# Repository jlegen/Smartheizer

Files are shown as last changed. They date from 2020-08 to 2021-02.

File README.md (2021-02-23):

# Smartheizer
## basic heating control

 I wanted some more control for my ancient heating system:
 * enable heating remotely before returning from holidays in winter :-)
 * record activity of heating system and hot water preparation
 * embed into my <a href="https://iobroker.net"> iobroker</a> system

 ##  The hardware in short:

* provides 3 isolated inputs for recording operation times (oil burner, pumps, hot water preparation)
* 3 relays to control heating operations, night setback remotely
* 3 plugs for DS18B20 temperature sensors
* socket for Wemos D1 Mini (or Pro)
* runs with <a href="https://tasmota.github.io/docs/"> Tasmota</a>

## Software needed
* Tasmota for the Wemos D1 on the PCB, which handles the GPIO inputs, Relays and temperature sensors
* a MQTT broker running somewhere, or a smart home software like iobroker or home assistant with MQTT enabled

## Tasmota config

Wemos D1 configuration in Tasmota:

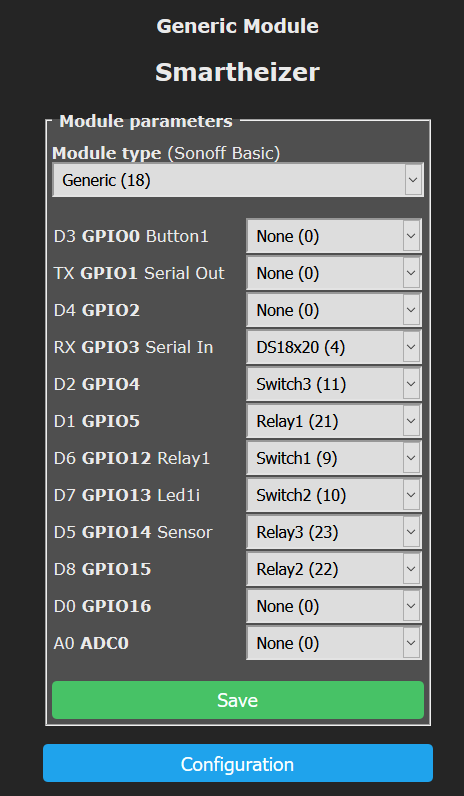
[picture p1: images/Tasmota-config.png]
Tasmota Wemos Config


Some Tasmota configurations can be easily applied using the web console. 

1) The GPIO polarity needs to be fixed:
<pre>
Backlog Switchmode1 2; Switchmode2 2; Switchmode3 2
</pre>

2) You also need to decouple the "Switches" (which are the GPIO inputs) from the Relays (it seems like a sort of 'tradition' with tasmota, that per default "Switch1" always triggers "Relay1" etc.).
<pre>
Rule1 on Switch1#state do Publish tele/tasmota_6E171C/SENSOR {"Time":"%timestamp%", "Burner":"%value%"} endon on Switch2#state do Publish tele/tasmota_6E171C/SENSOR {"Time":"%timestamp%", "Pump1":"%value%"} endon on Switch3#state do Publish tele/tasmota_6E171C/SENSOR {"Time":"%timestamp%", "Pump2":"%value%"} endon

Rule1 1
</pre>

Of course, you may chose different topics for MQTT. 
Btw, you don't even need to use these topics with your iobroker or other software - defining the "Rule1" alone enables Tasmota to send the switch states with MQTT as well.

New PCB revision
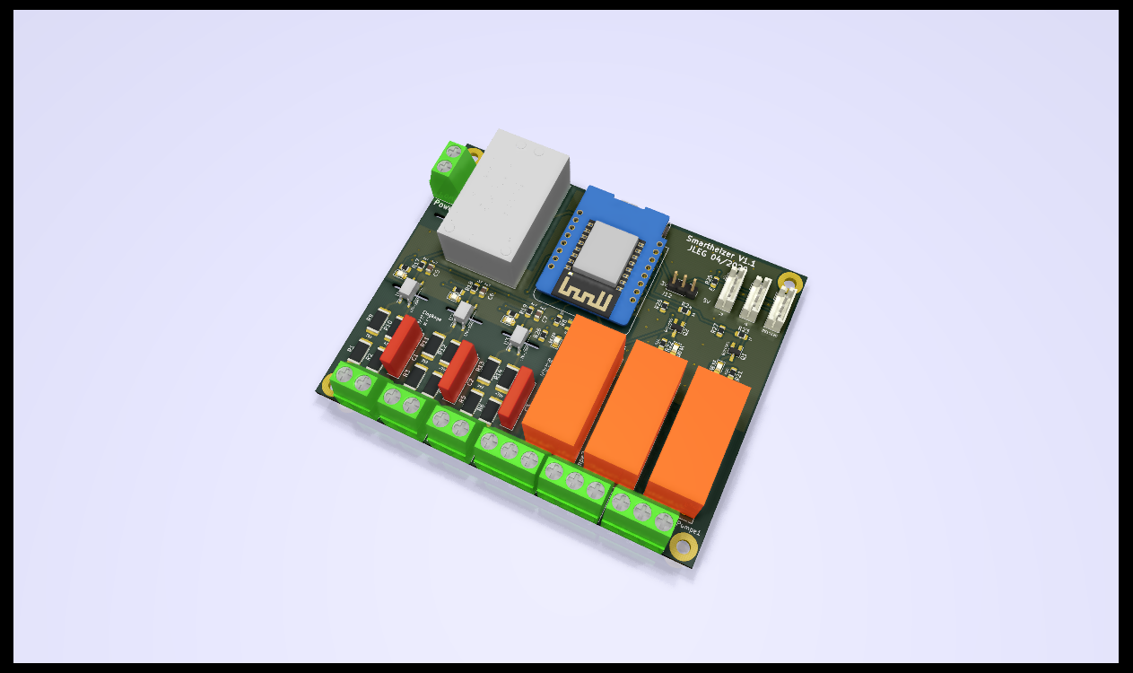
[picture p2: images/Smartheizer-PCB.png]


It works! :-)
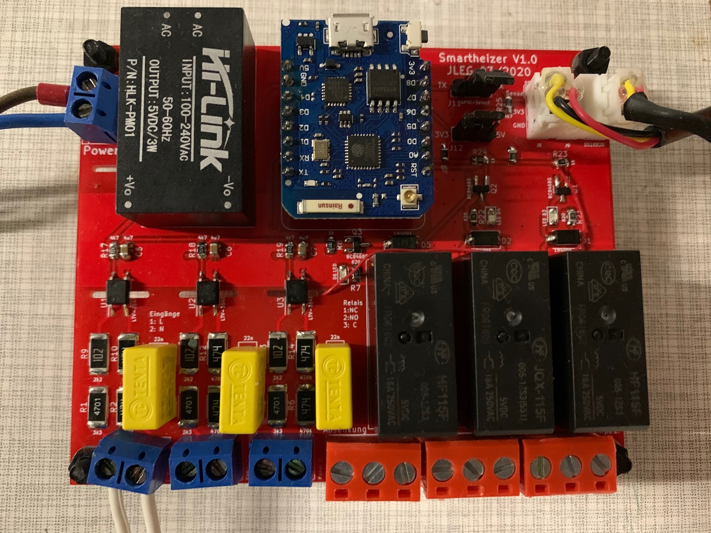
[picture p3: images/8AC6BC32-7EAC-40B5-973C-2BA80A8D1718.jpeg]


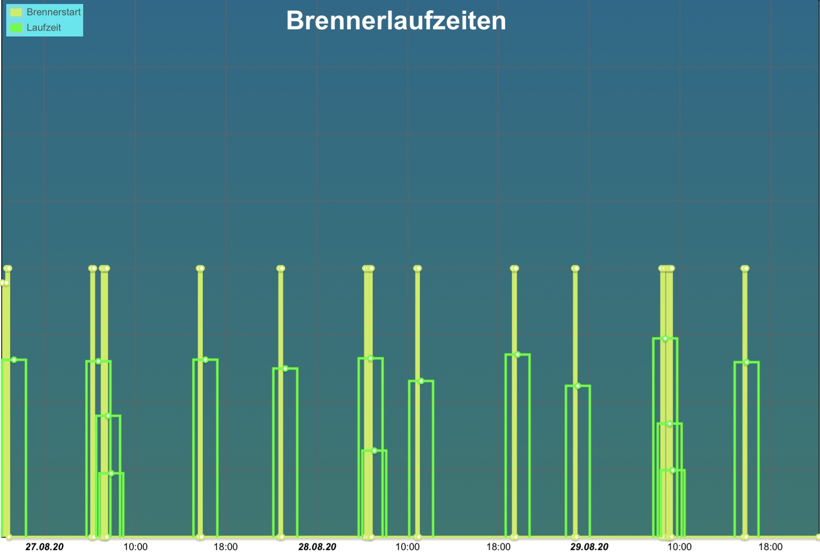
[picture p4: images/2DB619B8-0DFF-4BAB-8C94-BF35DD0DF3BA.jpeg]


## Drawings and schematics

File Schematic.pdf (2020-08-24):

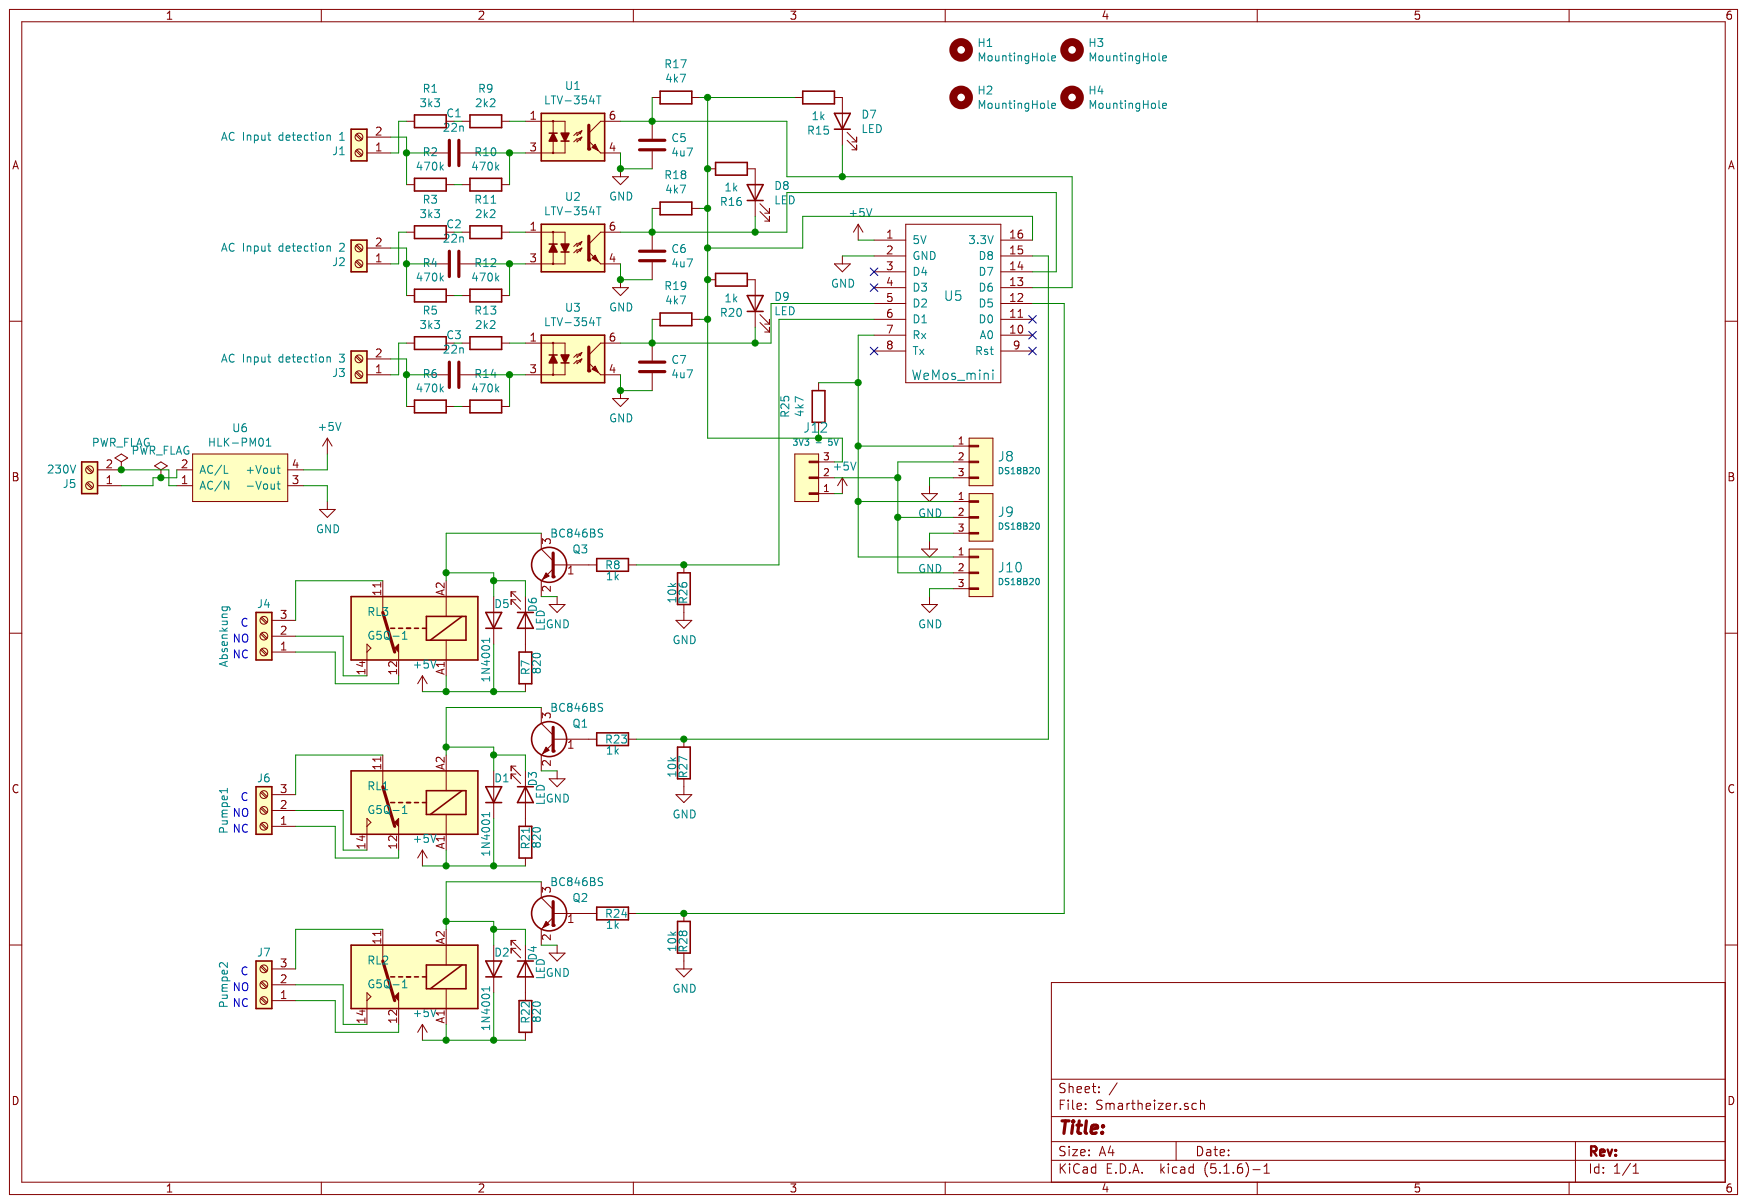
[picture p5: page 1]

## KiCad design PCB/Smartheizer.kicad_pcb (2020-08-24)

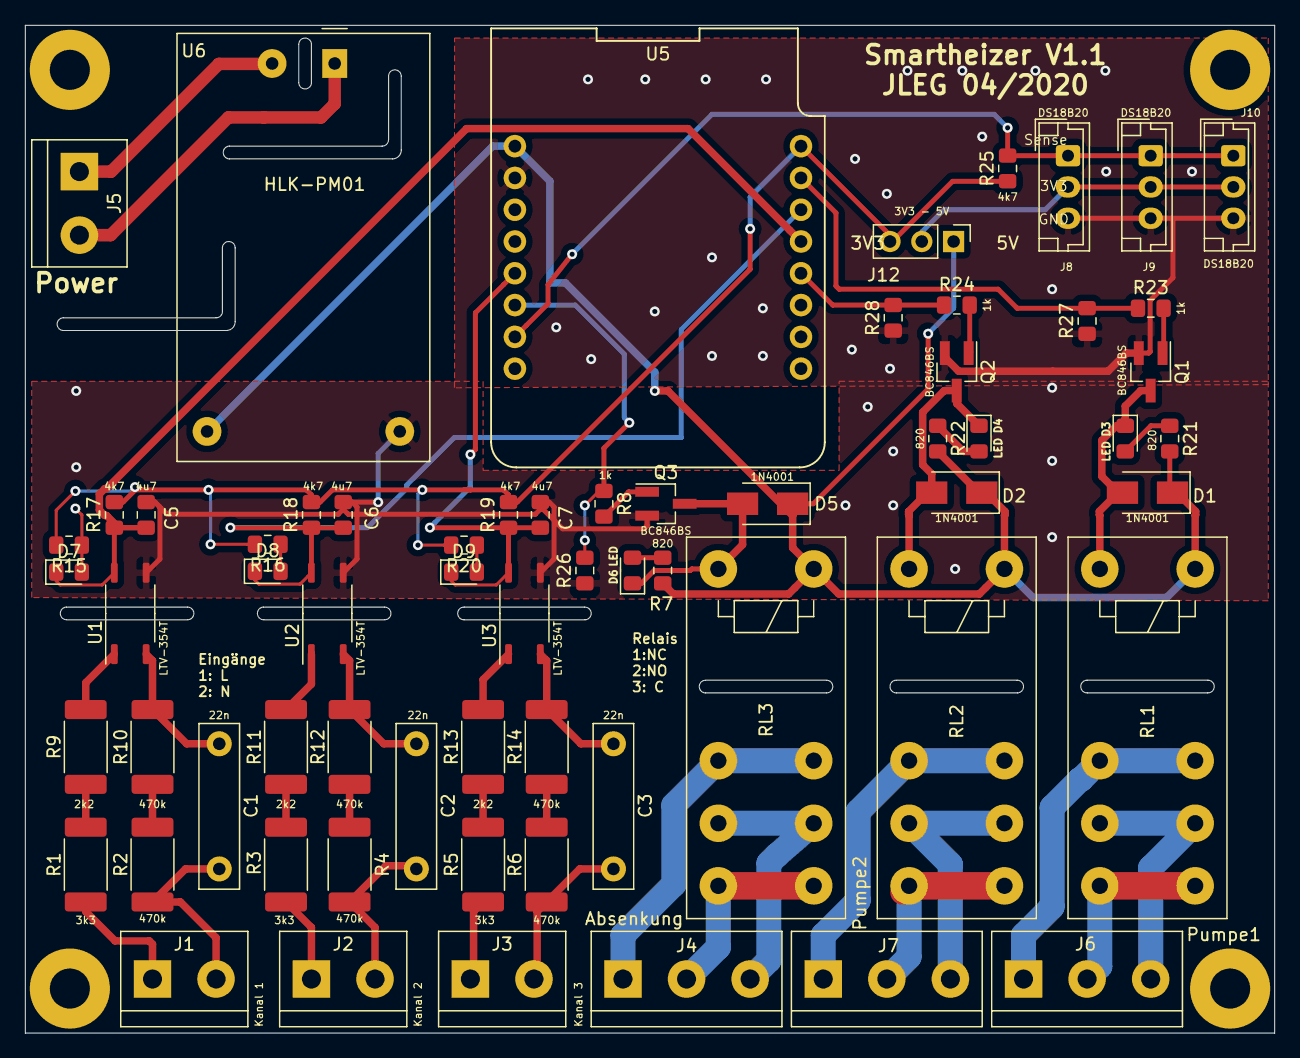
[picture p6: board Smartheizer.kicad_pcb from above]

Board: 2 copper layers, 99.8 x 80.5 mm, 69 parts (0 on the bottom side), 52 nets.

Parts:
C1, C2, C3: 22n; C_Rect_L13.0mm_W3.0mm_P10.00mm_FKS3_FKP3_MKS4
C5, C6, C7: 4u7; C_0805_2012Metric_Pad1.15x1.40mm_HandSolder
D1, D2, D5: 1N4001; D_SMA
D3, D4, D6, D7, D8, D9: LED; LED_0805_2012Metric_Pad1.15x1.40mm_HandSolder
H1, H2, H3, H4: MountingHole; MountingHole_3.2mm_M3_Pad
J1, J2, J3, J5: Screw_Terminal_01x02; TerminalBlock_bornier-2_P5.08mm
J4: Absenkung; TerminalBlock_bornier-3_P5.08mm
J6: Pumpe1; TerminalBlock_bornier-3_P5.08mm
J7: Pumpe2; TerminalBlock_bornier-3_P5.08mm
J8, J9, J10: DS18B20; JST_EH_B03B-EH-A_1x03_P2.50mm_Vertical
J12: 3V3 - 5V; PinHeader_1x03_P2.54mm_Vertical
Q1, Q2, Q3: BC846BS; SOT-23_Handsoldering
R1, R3, R5: 3k3; R_2512_6332Metric_Pad1.52x3.35mm_HandSolder
R2, R4, R6, R10, R12, R14: 470k; R_2512_6332Metric_Pad1.52x3.35mm_HandSolder
R7, R21, R22: 820; R_0805_2012Metric_Pad1.15x1.40mm_HandSolder
R8, R15, R16, R20, R23, R24: 1k; R_0805_2012Metric_Pad1.15x1.40mm_HandSolder
R9, R11, R13: 2k2; R_2512_6332Metric_Pad1.52x3.35mm_HandSolder
R17, R18, R19, R25: 4k7; R_0805_2012Metric_Pad1.15x1.40mm_HandSolder
R26, R27, R28: 10k; R_0805_2012Metric_Pad1.15x1.40mm_HandSolder
RL1, RL2, RL3: G5Q-1; Relay_SPDT_Schrack-RP-II-1-16A-FormC_RM5mm
U1, U2, U3: LTV-354T; SOIC-4_4.55x3.7mm_P2.54mm
U5: WeMos_mini; wemos-d1-mini-with-pin-header-and-connector
U6: HLK-PM01; Converter_ACDC_HiLink_HLK-PMxx

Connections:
+5V: D1.1, D2.1, D5.1, J12.1, R7.2, R21.2, R22.2, RL1.A1, RL2.A1, RL3.A1, U5.1, U6.4
GND: C5.2, C6.2, C7.2, J8.3, J9.3, J10.3, Q1.2, Q2.2, Q3.2, R26.1, R27.1, R28.1, U1.4, U2.4, U3.4, U5.2, U6.3
unnamed: C1.1, R10.1, U1.3
unnamed: C1.2, J1.2, R2.2
unnamed: C2.1, R12.1, U2.3
unnamed: C2.2, J2.2, R4.2
unnamed: C3.1, R14.1, U3.3
unnamed: C3.2, J3.2, R6.2
unnamed: C5.1, D7.1, R17.1, U1.6, U5.13
unnamed: C6.1, D8.1, R18.1, U2.6, U5.14
unnamed: C7.1, D9.1, R19.1, U3.6, U5.5
unnamed: D1.2, D3.1, Q1.3, RL1.A2
unnamed: D2.2, D4.1, Q2.3, RL2.A2
unnamed: D3.2, R21.1
unnamed: D4.2, R22.1
unnamed: D5.2, D6.1, Q3.3, RL3.A2
unnamed: D6.2, R7.1
unnamed: D7.2, R15.1
unnamed: D8.2, R16.1
unnamed: D9.2, R20.1
unnamed: J1.1, R1.2
unnamed: J2.1, R3.2
unnamed: J3.1, R5.2
unnamed: J4.1, RL3.12
unnamed: J4.2, RL3.14
unnamed: J4.3, RL3.11
unnamed: J5.1, U6.2
unnamed: J5.2, U6.1
unnamed: J6.1, RL1.12
unnamed: J6.2, RL1.14
unnamed: J6.3, RL1.11
unnamed: J7.1, RL2.12
unnamed: J7.2, RL2.14
unnamed: J7.3, RL2.11
unnamed: J8.1, J9.1, J10.1, R25.2, U5.7
unnamed: J8.2, J9.2, J10.2, J12.2
unnamed: J12.3, R15.2, R16.2, R17.2, R18.2, R19.2, R20.2, R25.1, U5.16
unnamed: Q1.1, R23.2
unnamed: Q2.1, R24.2
unnamed: Q3.1, R8.2
unnamed: R1.1, R9.2
unnamed: R9.1, U1.1
unnamed: R2.1, R10.2
unnamed: R11.1, U2.1
unnamed: R3.1, R11.2
unnamed: R4.1, R12.2
unnamed: R13.1, U3.1
unnamed: R5.1, R13.2
unnamed: R6.1, R14.2
unnamed: R23.1, R27.2, U5.15
unnamed: R24.1, R28.2, U5.12
unnamed: R8.1, R26.2, U5.6

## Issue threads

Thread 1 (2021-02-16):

Platine

comtechnik, 2021-02-16:
Hallo,
gibt es die Platine bei ihnen zu kaufen?

jlegen, 2021-02-17:
Hallo, verkaufen tu' ich nichts - ich habe allerdings tatsächlich noch ein paar Platinen übrig, und ich kann gerne eine abgeben.

Gibt allerdings einen kleinen Haken an der Sache - die Platine entspricht der, die auf dem Bild zu sehen ist - inlusive den kleinen "Modifikationen" ;-) Soll heissen, Schaltplan und Layout sind zwar korrigiert, meine Platinenversion enthält aber noch ein paar Bugs, die aber leicht zu beheben sind. Beim mir läuft die Schaltung nun seit fast einem Jahr 24/7 ohne Ausfall.

Die Änderungen betreffen die Relais: Da hatte ich blöderweise die Pull-Down-Widerstände am GPIO vergessen, und ausserdem eines der Relais an einen ESP-GPIO gehängt, der beim Booten toggelt, d.h. das Relais "zuckt" beim Booten. Die Pull-Downs können recht einfach jeweils zwischen die Transistor-Basen und der Massefläche gesetzt werden, die GPIO-Änderung ist einfach an den Wemos-Sockel gefädelt...

Was ich nicht behoben habe, weil ich's nicht benötige: Ausgangsseitig haben die Relaiskontakte keinerlei Snubber/Filter, d.h. wollte man da grössere Lasten schalten, sollte man noch etwas entstören.

Ach ja, und die JST-Buchsen für die Temperatursensoren (bzw. die Footprints dafür) sind auf dieser Platinenversion etwas zu eng gesetzt, es passen zwar 3 DS18B20 drauf, man muss aber etwas "quetschen"...

Falls immer noch Interesse besteht, Bescheid sagen - ich schicke gerne einen Umschlag mit Platine...

mucke46, 2023-11-04:
Hallo,
ich bin sehr an einer "Smartheizer-Platine" interessiert.
Bitte melde dich, wenn du noch eine "übrig" hast.

B.G.

jlegen, 2023-11-06:
> Hallo, ich bin sehr an einer "Smartheizer-Platine" interessiert. Bitte melde dich, wenn du noch eine "übrig" hast.

Theoretisch ja - praktisch müsste ich die erstmal wieder finden 🤷‍♂️ - hatte ich zuletzt vor 3 Jahren in der Hand…
Ich schaue mal.

>
> B.G.

mucke46, 2023-11-06:
Oha, danke sehr für die Rückmeldung, die Buderus Ecomatic ist schon sehr speziell, war aber schon sehr modern (1995).
Viel erfolg bei der suche...
Gruß

mucke46, 2023-11-09:
Vielen Dank für deine Hilfe. Ich habe inzwischen eine eigenes Design gefunden.Die Platine benötige ich nicht mehr.Beste GrüßeJ, S.Von meinem/meiner Galaxy gesendet
-------- Ursprüngliche Nachricht --------Von: jlegen ***@***.***> Datum: 06.11.23  20:29  (GMT+01:00) An: jlegen/Smartheizer ***@***.***> Cc: mucke46 ***@***.***>, Comment ***@***.***> Betreff: Re: [jlegen/Smartheizer] Platine (#1)

Hallo, ich bin sehr an einer "Smartheizer-Platine" interessiert. Bitte melde dich, wenn du noch eine "übrig" hast.

Theoretisch ja - praktisch müsste ich die erstmal wieder finden 🤷‍♂️ - hatte ich zuletzt vor 3 Jahren in der Hand…
Ich schaue mal.

B.G.

—Reply to this email directly, view it on GitHub, or unsubscribe.You are receiving this because you commented.Message ID: ***@***.***>

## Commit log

2020-08-24 initial upload of PCB
    Kicad files complete
    [Smartheizer.kicad_pcb, Smartheizer.sch]
2020-08-26 add switchmode config
2020-08-28 Add pcb image
    Populated pcb in action
2020-08-28 Added final pcb
2021-02-23 added pcb img
    PCB rendered
